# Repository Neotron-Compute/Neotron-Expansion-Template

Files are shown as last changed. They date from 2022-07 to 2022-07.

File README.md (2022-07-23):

# Neotron Expansion Template

This repository contains a template PCB you can use as the start of a new Neotron Expansion Card design.

It contains an MCP23S17 SPI I/O expander, connected to the SPI bus. It also contains an I²C EEPROM connected to the I²C bus and the unique slot address lines. The I/O expander has eight LEDs and eight switches fitted.

There is a jumper which will allow you to program the EEPROM from your Neotron system. Normally this jumper is not fitted, making the EEPROM read-only. The contents of the EEPROM are TBD, but will describe the expansion card to the Neotron OS so that it can be auto-configured and any necessary drivers loaded.

## Using this template

To use this template, simply copy the files in this repository and edit away! You'll probably want to delete everything on the schematic except the edge connector and the EEPROM (unless you really need an SPI I/O exander...).

## Licence

This schematic and PCB design is Copyright (c) 2022 The Neotron Developers, et al.



This work is licensed under a [Creative Commons Attribution 4.0 International License](http://creativecommons.org/licenses/by/4.0/).

## Contribution Agreement

Unless you explicitly state otherwise, any contribution intentionally submitted for inclusion in the work by you, as defined in the Apache-2.0 license, shall be licensed as above, without any additional terms or conditions.

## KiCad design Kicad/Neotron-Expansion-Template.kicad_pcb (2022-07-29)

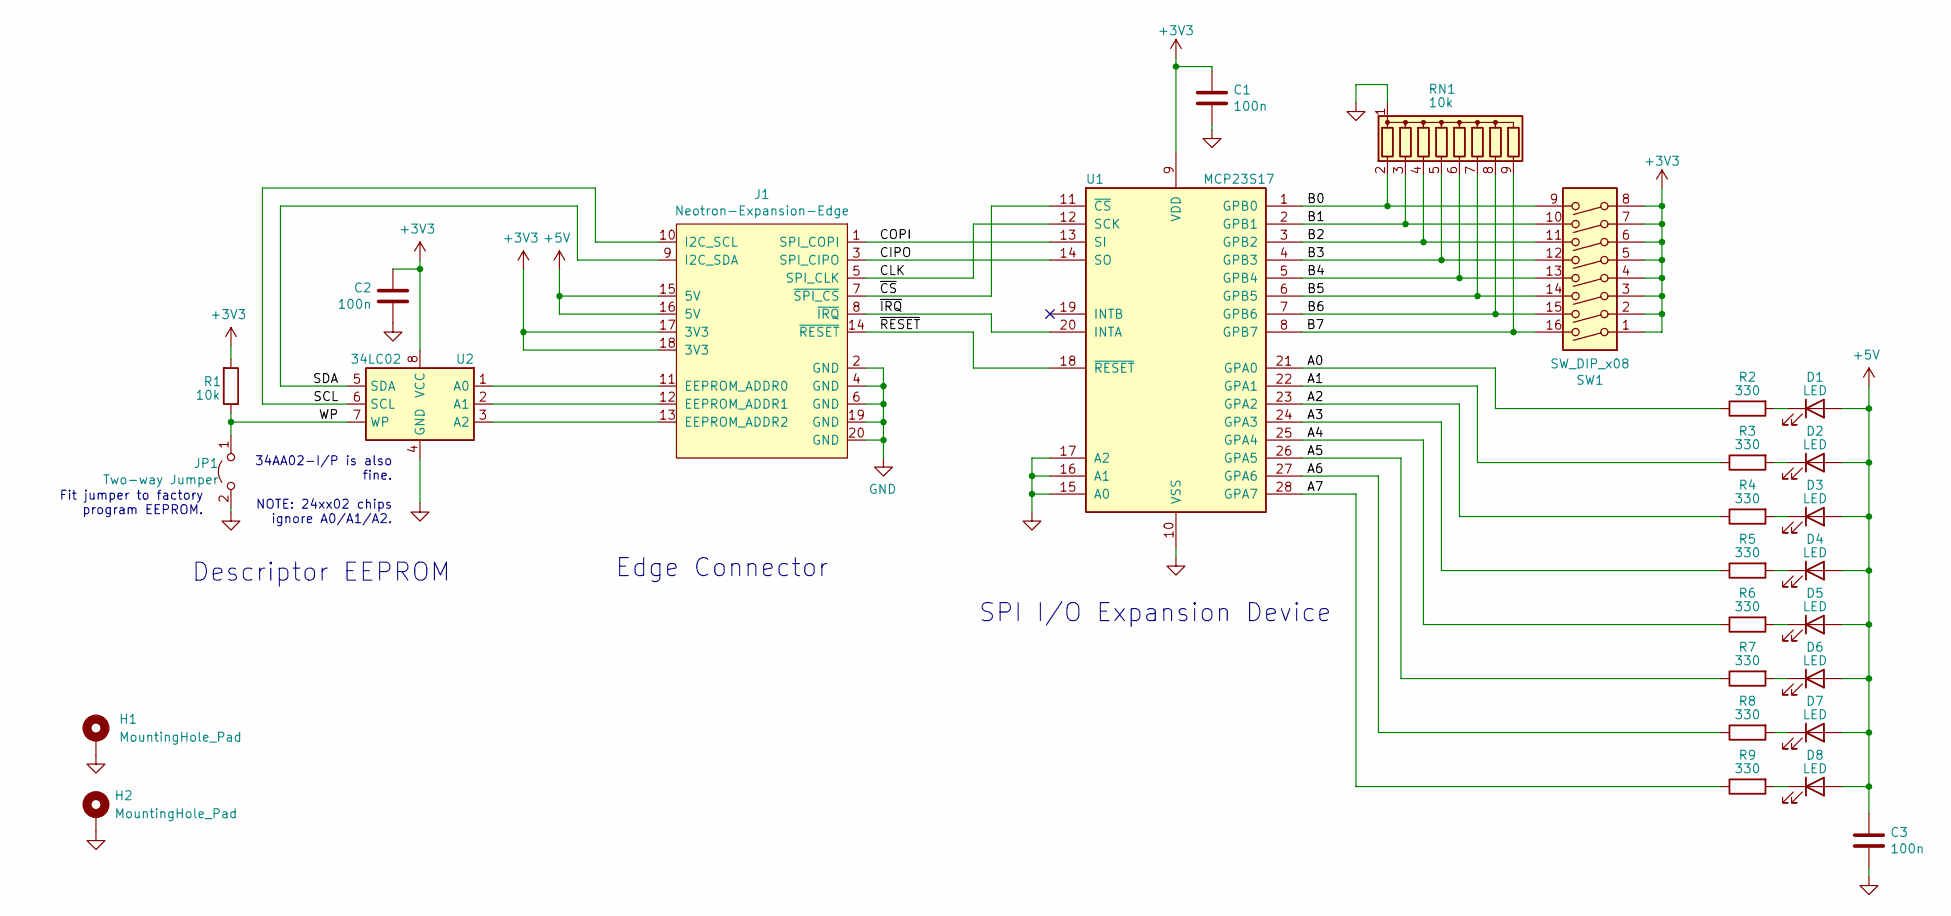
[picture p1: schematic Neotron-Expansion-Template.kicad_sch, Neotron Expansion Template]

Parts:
C1, C2: 100n; C_Disc_D7.0mm_W2.5mm_P5.00mm; Voltage 10V; MPN C315C104M5U5TA; Digikey 399-4151-ND
C3: 100n; C_Disc_D7.0mm_W2.5mm_P5.00mm; Voltage 16V; MPN C315C104M5U5TA; Digikey 399-4151-ND
D1, D2, D3, D4, D5, D6, D7, D8: LED; LED_D3.0mm; MPN L314ED; Digikey 2460-L314ED-ND
H1, H2: MountingHole_Pad; MountingHole_2.7mm_M2.5_Pad
J1: Neotron-Expansion-Edge
JP1: Two-way Jumper; PinHeader_1x02_P2.54mm_Vertical
R1: 10k; R_Axial_DIN0207_L6.3mm_D2.5mm_P10.16mm_Horizontal; MPN CF14JT10K0; Digikey CF14JT10K0TR-ND
R2, R3, R4, R5, R6, R7, R8, R9: 330; R_Axial_DIN0207_L6.3mm_D2.5mm_P10.16mm_Horizontal; MPN CF14JT330R; Digikey CF14JT330RTR-ND
RN1: 10k; R_Array_SIP9; MPN 4609X-101-103LF; Digikey 4609X-101-103LF-ND
SW1: SW_DIP_x08; DIP-16_W7.62mm_LongPads; MPN DS01C-254-L-08BE; Digikey 2223-DS01C-254-L-08BE-ND
U1: MCP23S17; DIP-28_W7.62mm; MPN MCP23S17-E/SP; Digikey MCP23S17-E/SP-ND
U2: 34LC02; DIP-8_W7.62mm; MPN 34LC02-I/P; Digikey 34LC02-I/P-ND

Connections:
+3V3: C1.1, C2.1, J1.17 (3V3), J1.18 (3V3), R1.2, SW1.1, SW1.2, SW1.3, SW1.4, SW1.5, SW1.6, SW1.7, SW1.8, U1.9 (VDD), U2.8 (VCC)
+5V: C3.1, D1.2 (A), D2.2 (A), D3.2 (A), D4.2 (A), D5.2 (A), D6.2 (A), D7.2 (A), D8.2 (A), J1.15 (5V), J1.16 (5V)
/A0: R2.1, U1.21 (GPA0)
/A1: R3.1, U1.22 (GPA1)
/A2: R4.1, U1.23 (GPA2)
/A3: R5.1, U1.24 (GPA3)
/A4: R6.1, U1.25 (GPA4)
/A5: R7.1, U1.26 (GPA5)
/A6: R8.1, U1.27 (GPA6)
/A7: R9.1, U1.28 (GPA7)
/B0: RN1.2 (R1), SW1.9, U1.1 (GPB0)
/B1: RN1.3 (R2), SW1.10, U1.2 (GPB1)
/B2: RN1.4 (R3), SW1.11, U1.3 (GPB2)
/B3: RN1.5 (R4), SW1.12, U1.4 (GPB3)
/B4: RN1.6 (R5), SW1.13, U1.5 (GPB4)
/B5: RN1.7 (R6), SW1.14, U1.6 (GPB5)
/B6: RN1.8 (R7), SW1.15, U1.7 (GPB6)
/B7: RN1.9 (R8), SW1.16, U1.8 (GPB7)
/CIPO: J1.3 (SPI_CIPO), U1.14 (SO)
/CLK: J1.5 (SPI_CLK), U1.12 (SCK)
/COPI: J1.1 (SPI_COPI), U1.13 (SI)
/SCL: J1.10 (I2C_SCL), U2.6 (SCL)
/SDA: J1.9 (I2C_SDA), U2.5 (SDA)
/WP: JP1.1 (A), R1.1, U2.7 (WP)
/~CS: J1.7 (~SPI_CS), U1.11 (~CS)
/~IRQ: J1.8 (~IRQ), U1.20 (INTA)
/~RESET: J1.14 (~RESET), U1.18 (~RESET)
GND: C1.2, C2.2, C3.2, H1.1, H2.1, J1.2 (GND), J1.4 (GND), J1.6 (GND), J1.19 (GND), J1.20 (GND), JP1.2 (B), RN1.1 (common), U1.10 (VSS), U1.15 (A0), U1.16 (A1), U1.17 (A2), U2.4 (GND)
unnamed: D1.1 (K), R2.2
unnamed: D2.1 (K), R3.2
unnamed: D3.1 (K), R4.2
unnamed: D4.1 (K), R5.2
unnamed: D5.1 (K), R6.2
unnamed: D6.1 (K), R7.2
unnamed: D7.1 (K), R8.2
unnamed: D8.1 (K), R9.2
unnamed: J1.11 (EEPROM_ADDR0), U2.1 (A0)
unnamed: J1.12 (EEPROM_ADDR1), U2.2 (A1)
unnamed: J1.13 (EEPROM_ADDR2), U2.3 (A2)

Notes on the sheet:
Edge Connector
34AA02-I/P is also fine. NOTE: 24xx02 chips ignore A0/A1/A2.
Descriptor EEPROM
Fit jumper to factory program EEPROM.
SPI I/O Expansion Device

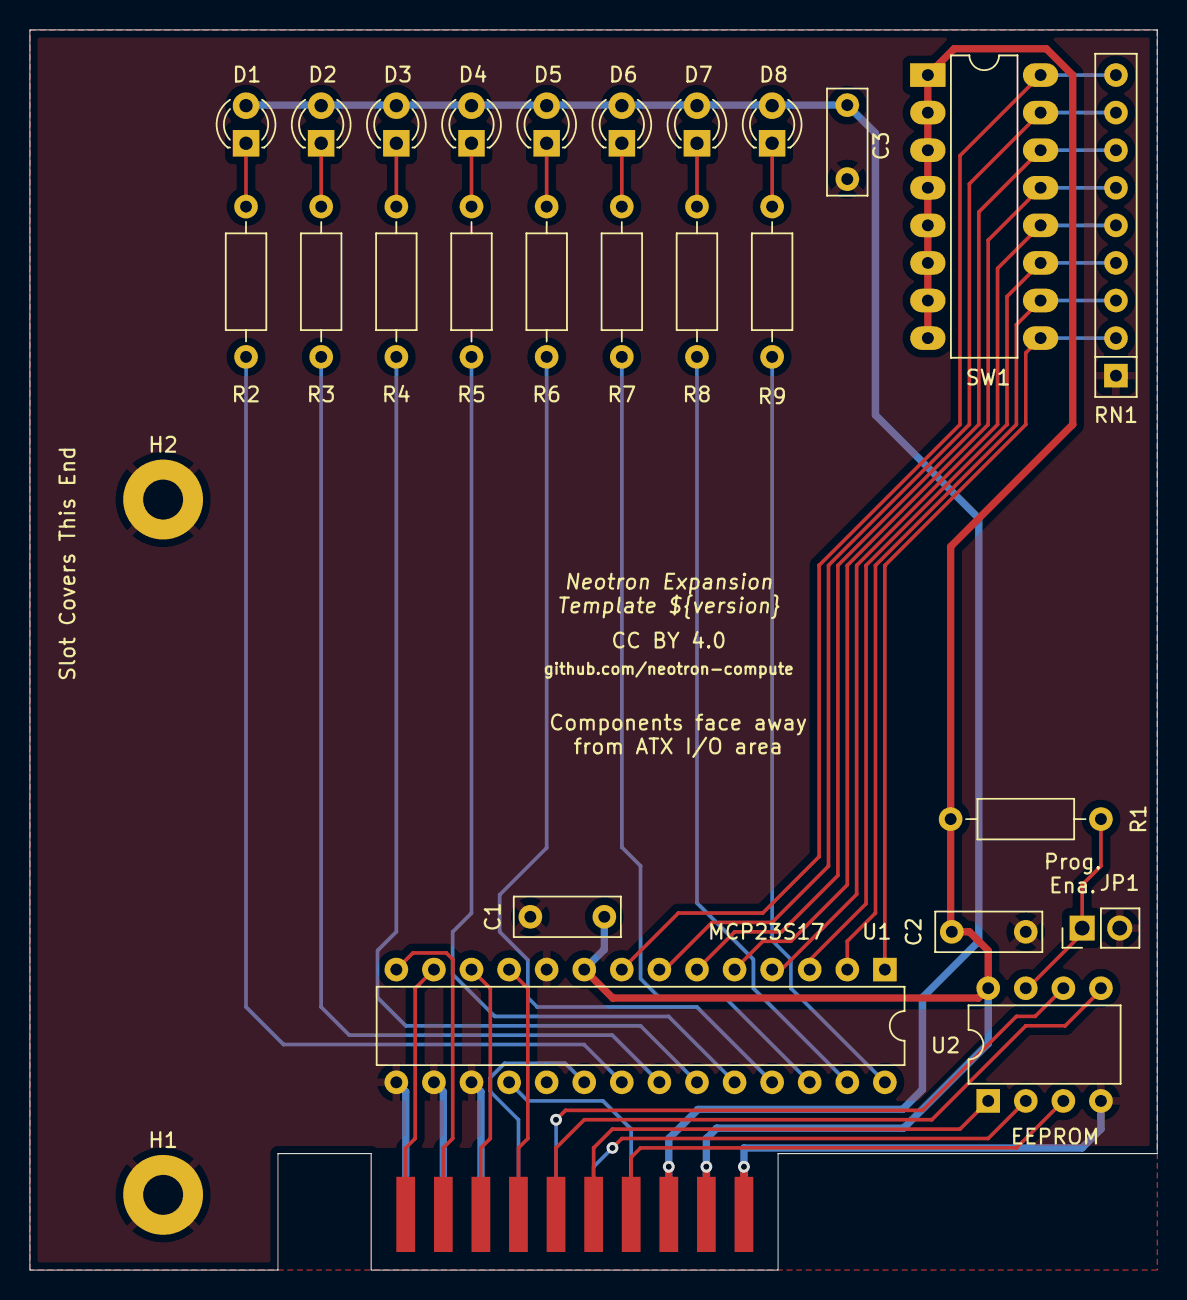
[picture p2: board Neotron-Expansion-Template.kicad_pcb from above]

Board: 2 copper layers, 76.2 x 83.8 mm, 28 parts (0 on the bottom side), 39 nets.

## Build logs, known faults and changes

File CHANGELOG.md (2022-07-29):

# Changelog

## Unreleased Changes

* None

## v0.7.0

* Make board larger.
* Add screwholes.
* Adjust to fit new expansion connector position on Neotron Pico 1.0.

## v0.6.1

* Allow KiBot to set version/date field.

## v0.6.0

* Fixed power supply to MCP23S17
* Moved around components

## v0.5.0

* First version

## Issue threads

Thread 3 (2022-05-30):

MCP23S17 is powered backwards

thejpster, 2022-05-30:
VDD is grounded and VSS is connected to 3.3V. The chip gets very very hot.

This appears to be because the symbol was rotated instead of being mirrored.

thejpster, 2022-07-22:
Fixed by #5

Closed 2022-07-22.

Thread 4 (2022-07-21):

Add screw holes

thejpster, 2022-07-21:
We need holes so the card can be bolted to a bracket. This turn allows it to be screwed into a PC case so it doesn't flop about.

thejpster, 2022-07-29:
Closed by #7

Closed 2022-07-29.

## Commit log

2021-08-18 First draft.
    [Neotron-Expansion-Template.kicad_pcb, Neotron-Expansion-Template.sch]
2021-08-18 Add kicad-exports.
    [Neotron-Expansion-Template.sch]
2022-07-22 Updated to KiCAD 6 and re-worked.
    Power is the right way around now....
    [Neotron-Expansion-Template.kicad_pcb, Neotron-Expansion-Template.kicad_sch]
2022-07-22 Bring over new CI code.
    Taken from Neotron Pico.
2022-07-23 Fix date/version fields.
    They must be set as ${field}, so Kibot can replace them.
    [Neotron-Expansion-Template.kicad_pcb, Neotron-Expansion-Template.kicad_sch]
2022-07-29 Adjusted board size to suit Neotron Pico 1.0.0.
    Has holes for a random backplate I found.
    [Neotron-Expansion-Template.kicad_pcb, Neotron-Expansion-Template.kicad_sch]
2022-07-29 Fix DRC issues.
    [Neotron-Expansion-Template.kicad_pcb, Neotron-Expansion-Template.kicad_sch]

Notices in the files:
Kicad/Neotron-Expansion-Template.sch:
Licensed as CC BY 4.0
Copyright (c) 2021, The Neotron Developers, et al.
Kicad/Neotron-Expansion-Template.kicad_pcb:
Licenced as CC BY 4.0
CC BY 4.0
